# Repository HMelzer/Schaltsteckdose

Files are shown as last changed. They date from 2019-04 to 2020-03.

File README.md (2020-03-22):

# Funkschaltsteckdose für HomeMatic/RaspberryMatik

## Gehäuse
Auf der Basis des [ELV-Gehäuses OM54](https://de.elv.com/elv-design-stecker-steckdosen-gehaeuse-om-54-c-mit-tasterstoessel-und-led-leuchtfeld-083421)
und des dazugehörigen [Steckdoseneinsatzes](https://de.elv.com/schutzkontakt-stecker-steckdosen-einsatz-ohne-sicherungshalter-083422) wird hier eine Funk-Schaltsteckdose vorgestellt,
die auf der Grundlage von AsksinPP arbeitet und voll in das HomeMatic/RaspberryMatik-Programm integriert werden kann.

## Platine
Die Platine wurde mit KICAD entwickelt, die KICAD-Daten sind hier beigefügt.
Das nachfolgende Bild zeigt Vorder- und Rückseite der Leiterplatte, hier noch im Leiterplattenrahmen,
aus dem man die Leiterplatten spätestens dann trennen muss, wenn man den Steckdoseneinsatz montieren will.
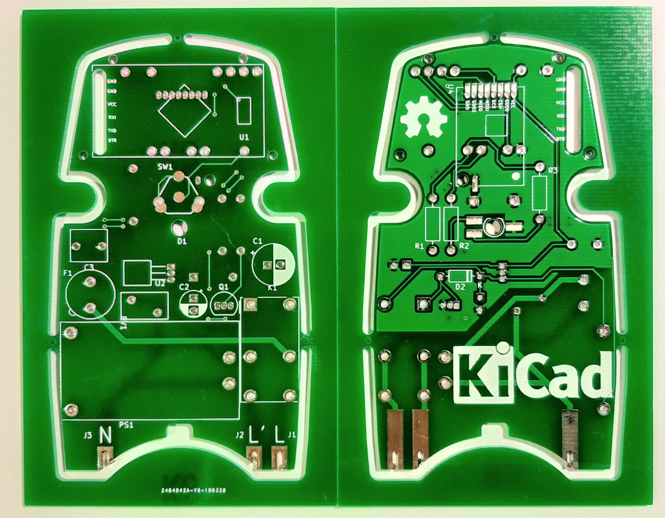
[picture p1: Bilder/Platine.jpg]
Leiterplatte


## Schaltung
Für die Stromversorgung wurde ein Baustein von Hi-Link verwendet, der primärseitig mit 100 - 240 V gespeist werden und sekundärseitig 12 V DC bei 0,25 A liefern kann.
[HMK-PM12](https://de.aliexpress.com/item/32960181700.html?spm=a2g0s.9042311.0.0.19304c4d0xYQv4).
Wegen der engen Platzverhältnisse kam ein Relais G6B-2214P der Fa. Omron mit 12 V Spulenspannung zum Einsatz, dass 5 A schalten kann.<br/>
Herzstück ist, wie in den meisten HomeMatic/RaspberryMatic-Projekten, ein ArduinoProMini in der 3,3 V - Variante, der eine große Verbreitung erlangt hat und bei vielen Anbietern zu bekommen ist.
Die erforderliche Spannung für diesen und den Sendebaustein erzeugt ein LDO aus der 12 V - Spannung.<br/>
Im Schaltplan sind alternativ zwei Sendebausteine aufgeführt.
Das ist zum einen der klassische CC1101, der in vielen Projekten zur Anwendung kommt.
Da es damit in der Vergangenheit immer wieder zu Problemen mit der Sende-/Empfangsfrequenz gekommen ist, vergleiche [Fehlerhafte CC1101 Module](https://asksinpp.de/Grundlagen/FAQ/Fehlerhafte_CC1101.html),
wurde hier in der praktische Ausführung ein anderes Modul, welches ebenfalls den CC1101 verwendet, eingesetzt.
Das Modul ist ein [E07_868MS10](http://www.ebyte.com/en/product-view-news.aspx?id=180) der Fa. Ebyte.

## Ausführung/Montage
Beim Zusammenfügen des Gehäuses und des Steckdoseneinsatzes hat es sich gezeigt, dass die Öffnung im Gehäusedeckel geringfügig nachgearbeitet werden muss, um den Steckdoseneinsatz passfähig montieren zu können.
Mit dem Gehäuse lose mitgeliefert werden der Tastereinsatz, ein Lichtleiter und ein "Knackfrosch", der als Taster dient. Beim Einsetzen des Lichtleiters in den Tastereinsatz ist ein wenig Fingerspitzengefühl erforderlich
und man sollte vorsichtig zu Werke gehen, um nichts abzubrechen.
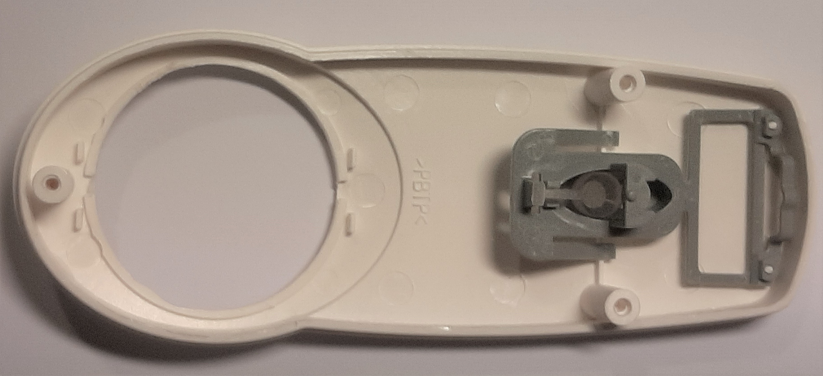
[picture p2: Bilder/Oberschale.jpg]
Oberschale
Das Bild zeigt die Oberschale mit montiertem Taster und Lichtleiter.<p/> <p/>
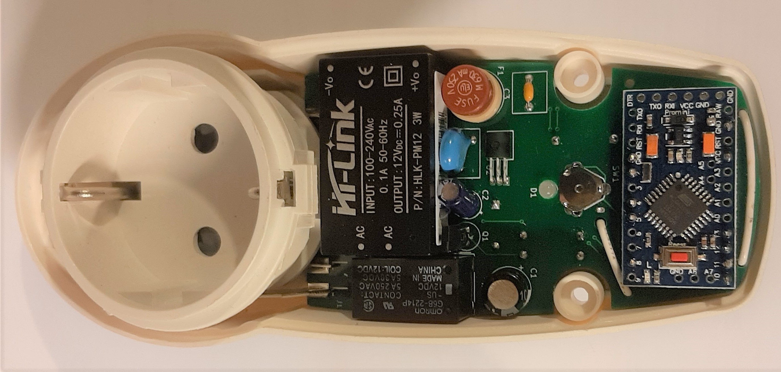
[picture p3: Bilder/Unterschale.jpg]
Unterschale
Im nachfolgenden Bild sieht man die Unterschale mit der bereits montierten Leiterplatte.<p/> <p/>
Der "Knackfrosch" wurde einfach in die dafür vorgesehenen Löcher auf der Vorderseite der Leiterplatte eingesetzt und die Laschen auf der Rückseite leicht umgebogen.
**Er darf nicht verlötet werden**.
Vor den eigentlichen Lötarbeiten empfiehlt es sich, die Leiterplatte aus dem Rahmen zu lösen und den Leiterplattenrand an den ehemaligen Verbindungsstellen zu glätten. Die Passfähigkeit im Gehäuse sollte anschließend geprüft werden.
Das sollte auch im Zusammenwirken mit dem Steckdoseneinsatz erfolgen und hierbei sollten auch gleich die Kontaktstreifen des Steckdoseneinsatzes an den Stellen gekennzeichnet werden, an denen diese gekürzt werden müssen.
Alle verwendeten Bauelemente sind als THT ausgeführt, sodass sich die Lötarbeiten einfach gestalten sollten. Die Verteilung auf Vorder- und Rückseite ist dem engen Platzverhältnis geschuldet, welches durch den integrierten Taster
bedingt ist.
Eine Besonderheit stellt die LED dar, da es sich um eine Bauform handelt, die zwei LED, rot und grün, in einem Gehäuse vereinigt.
Es handelt sich hierbei um eine 3 mm Diode, die von der Leiterplattenrückseite montiert werden muss, wobei diese nicht mehr als 1 mm auf der Vorderseite hervorstehen darf, da sich ansonsten der Taster nicht tief genug drücken lässt.
Alternativ kann man allerdings auch den Lichtleiter, beispielsweise mittels Dremel, um ca. 2 mm kürzen. Die Anschlussdrähte der Diode sind dabei nahe am Gehäuse zu biegen. Auf die richtige Verschaltung der beiden Dioden ist zu achten. Im Projekt zum Einsatz kam eine **EVL 209SURSYGW** (Reichelt Elektronik).
Dafür gilt auch der Aufdruck auf der Platine.<br/>
Bevor der ArduinoProMini mit allen dafür vorgesehenen Stiften mit der Leiterplatte verlötet wird, muss man die Stiftleiste (8 x 1,27 mm) für den E07_868MS10 aufsetzen und verlöten, da die Lötpunkte unter dem Arduino zu liegen kommen.
Die Anschlussstifte für den ArduinoProMini sollten in dem Bereich, wo diese vom E07_868MS10 überdeckt werden, nicht so lang ausfallen, damit es keine Kurzschlüsse gibt. Der E07_868MS10 selbst wird dann mittels der Stiftleiste 8 x 1,27 mm
und einem einzelnen Stift für den Masseanschluss auf der Leiterplatte verlötet. Dadurch erhält der E07_868MS10 auch gleich den nötigen Abstand zur Leiterplatte.
Die erforderliche Antenne wird durch einen Schaltdraht der Länge 83 mm gebildet, welcher von oben durch das vorhandene Loch rechts neben dem "Knackfrosch" gesteckt und an dem verbliebenen Anschluss am E07_868MS10 angelötet wird.
Das freie Ende des Schaltdrahtes wird dann wechselseitig durch die vorhandenen Löcher neben und oberhalb des ArduinoProMini geführt.<p/>
Das folgende Bild zeigt die bestückte Rückseite mit bereits montiertem Steckdoseneinsatz. Die montierte LED ist gut zu erkennen, ebenso das Funkmodul und die verlegte Antenne.
Das geänderte Leiterplattenlayout oben links ist in den Daten bereits korrigiert.<p/>
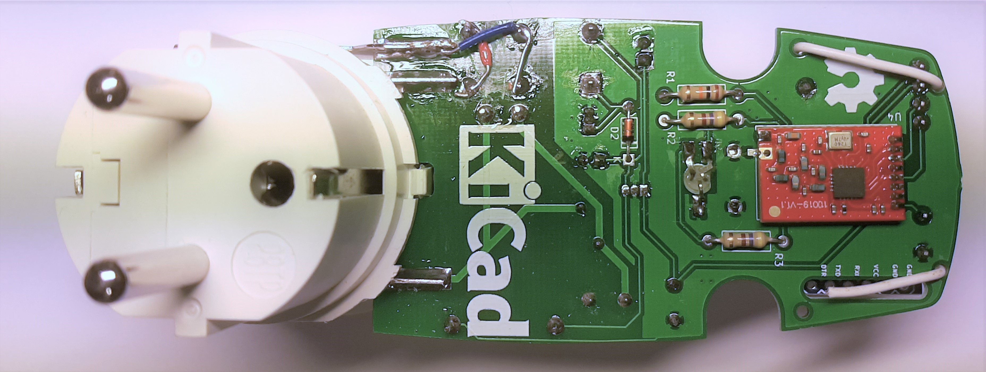
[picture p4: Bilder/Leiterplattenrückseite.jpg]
Leiterplattenrückseite
<p/>
Zum Schluss wird der Steckdoseneinsatz mit der Leiterplatte verlötet. Um die spätere Passfähigkeit zu erhalten, ist es empfehlenswert, Leiterplatte und Steckdoseneinsatz in das Gehäuse einzusetzen und die Laschen oberseitig mit wenig
Lötzinn zu fixieren. Nach der Entnahme aus dem Gehäuse müssen die Laschen großflächig, sowohl auf der Ober- wie auch auf der Unterseite mit der Leiterplatte verlötet werden.

## Programmierung
Die Datei [HM-LC-Sw1-Pl-DN-R1.ino](https://github.com/HMelzer/Schaltsteckdose/blob/master/HM-LC-Sw1-Pl-DN-R1/HM-LC-Sw1-Pl-DN-R1.ino) enthält das entsprechende Programm, welches in den ArduinoProMini eingespielt werden muss.
Im Bereich ab Zeile 43 sind wie immer die entsprechenden Anpassungen für "Device ID" und "Device Serial" vorzunehmen.<br/>
Die eigentliche Programmierung erfolgt dann mittels der Programmiersoftware für den Arduino in der entsprechend neusten Version und einem FTDI Adapter FT232RL USB zu TTL.
Bei Verwendung eines solchen, beispielsweise der Fa. AZ-Delivery, kann man die daran vorhandene Stiftleiste gleich in die dafür vorgesehenen Löcher am ArduinoProMini stecken und so die Programmierung auf einfache Weise vornehmen.

## Anlernen
Nachdem man die Programmierung abgeschlossen und das Gehäuse mittels der mitgelieferten Schrauben geschlossen hat, kann man die erste Funktionsprobe vornehmen. Hat man die Schaltsteckdose mittels der Steckerstifte mit dem Stromnetz verbunden,
sollte zunächst das Ein- und wieder Ausschalten über den Taster möglich sein. Im Aus-Zustand sollte keine LED leuchten, im Ein-Zustand die grüne LED.<br/>
Das Anlernen erfolgt nun in der bekannten Weise, dass man in der Zentrale die Anlernfunktion für Geräte startet und an der Schaltsteckdose den Taster kurz betätigt (rote LED blinkt), wobei dadurch die Schaltsteckdose ebenfalls in den Anlernmodus
versetzt wird und nach kurzer Zeit die blinkende LED das Blinken einstellen sollte. Nachdem der Anlernmodus in der Zentrale abgelaufen ist, sollte sich das neue Gerät im Posteingang der Zentrale wiederfinden,
woraus es dann übernommen, eingestellt und programmiert werden kann.

## Lizenz
Der Inhalt dieses Repository unterliegt der aktuellen Lizenz nach Creative Commons - [https://creativecommons.org/licenses/by-nc-sa/4.0/deed.de](https://creativecommons.org/licenses/by-nc-sa/4.0/deed.de).

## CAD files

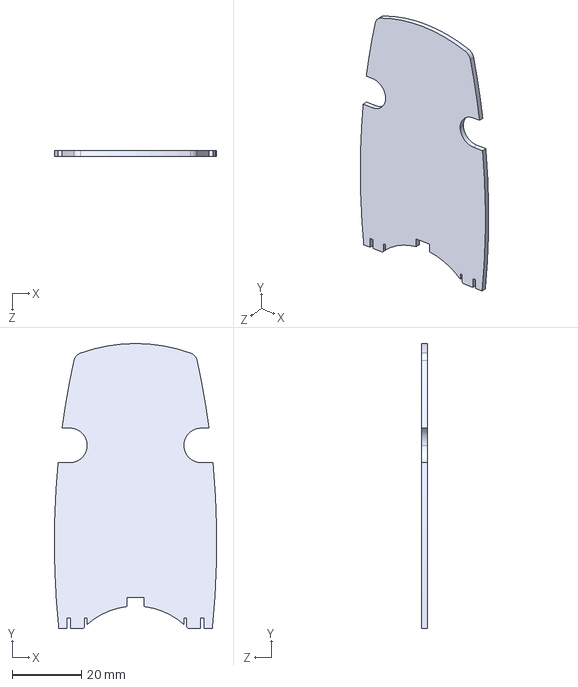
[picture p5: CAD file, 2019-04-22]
Leiterplattenkontur.STEP
47.0 x 82.5 x 1.60 mm

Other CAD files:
Leiterplattenkontur.DXF
Leiterplattenkontur.SLDPRT

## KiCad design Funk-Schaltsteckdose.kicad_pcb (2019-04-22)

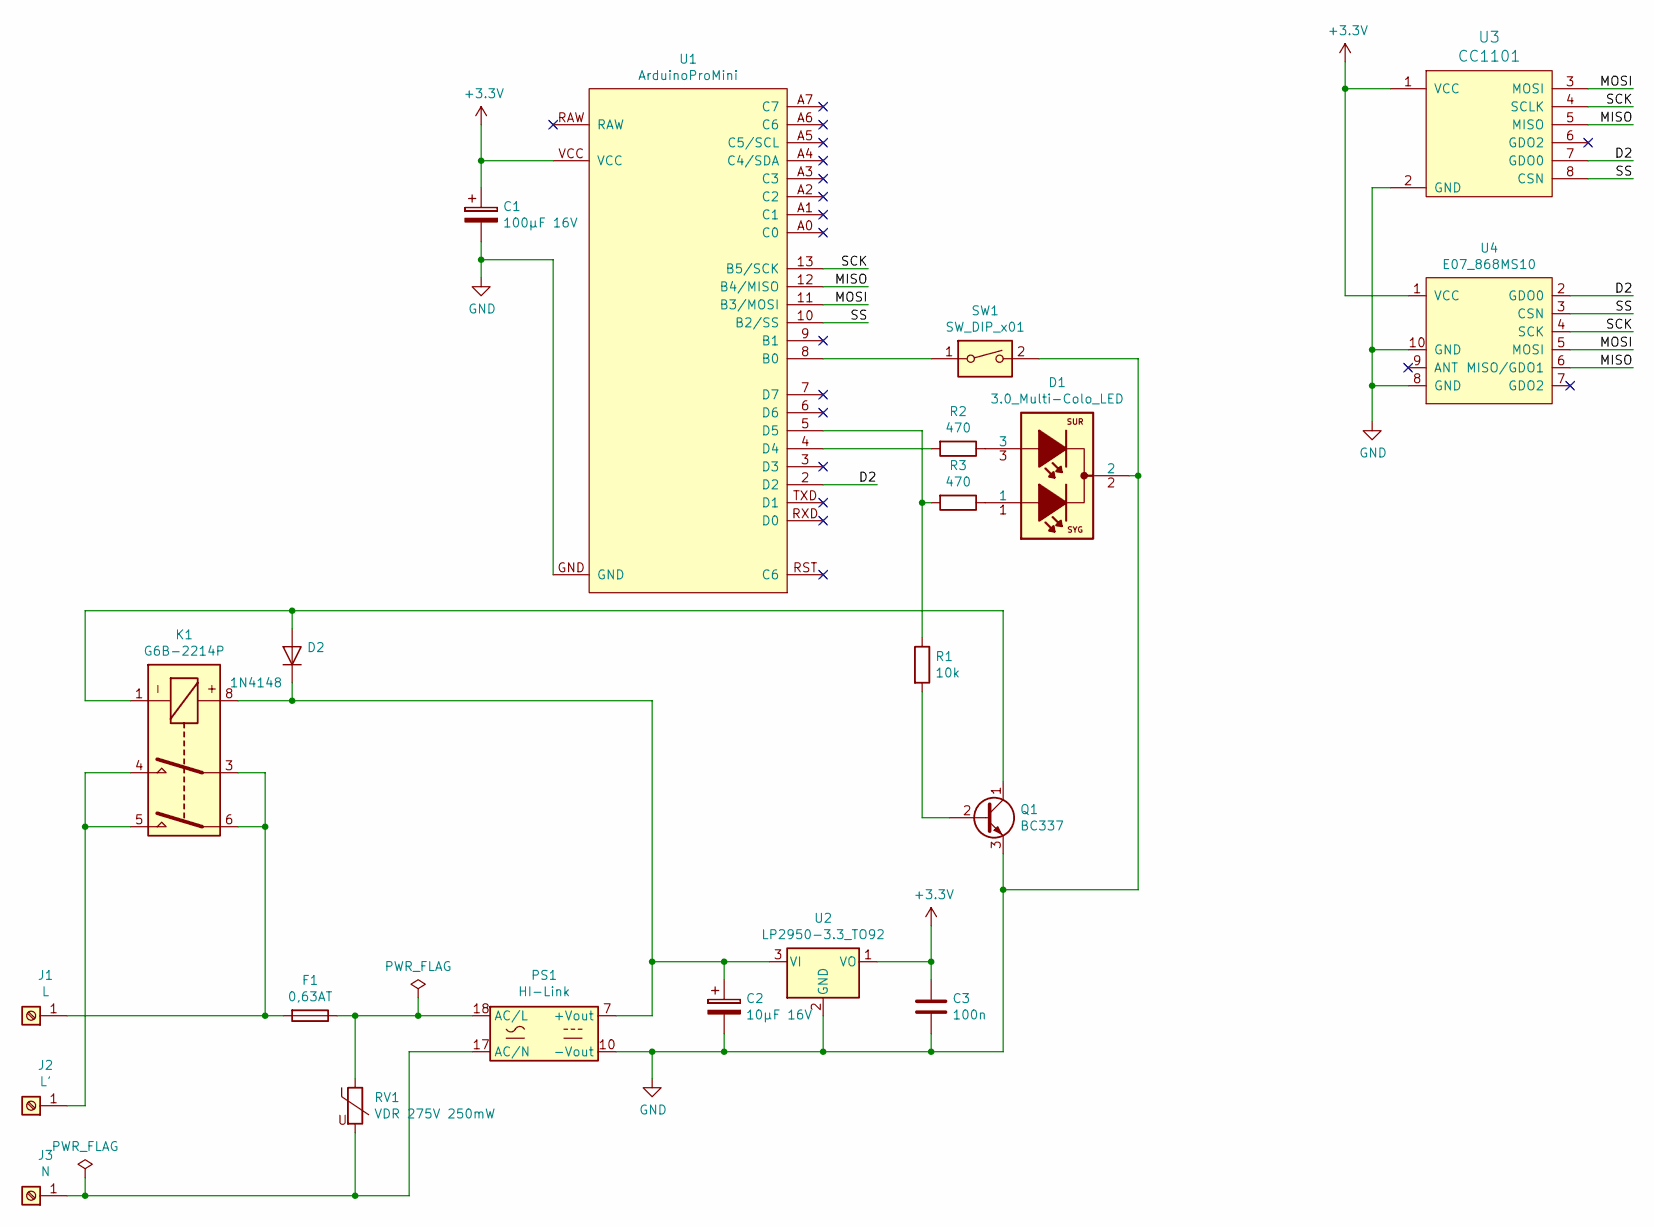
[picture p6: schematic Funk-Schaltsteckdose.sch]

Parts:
C1: 100µF 16V; CP_Radial_D8.0mm_P2.50mm
C2: 10µF 16V; CP_Radial_D5.0mm_P2.50mm
C3: 100n; C_Rect_L7.0mm_W6.0mm_P5.00mm
D1: 3.0_Multi-Colo_LED; Durchsteck_LED_THT_3,0
D2: 1N4148; D_DO-35_SOD27_P7.62mm_Horizontal
F1: 0,63AT; Fuseholder_TR5_Littelfuse_No560_No460
J1: L; Kontaktstreifen
J2: L'; Kontaktstreifen
J3: N; Kontaktstreifen
K1: G6B-2214P; Relay_DPST_Omron_G6B-2214
PS1: HI-Link
Q1: BC337; TO-92_Inline
R1: 10k; R_Axial_DIN0207_L6.3mm_D2.5mm_P10.16mm_Horizontal
R2, R3: 470; R_Axial_DIN0207_L6.3mm_D2.5mm_P10.16mm_Horizontal
RV1: VDR 275V 250mW; RV_Disc_D9mm_W5.2mm_P5mm
SW1: SW_DIP_x01; Schaltkontakt
U1: ArduinoProMini; ArduinoProMini_modif.
U2: LP2950-3.3_TO92; TO-92_Inline_Horizontal1
U3: CC1101
U4: E07_868MS10

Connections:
+3V3: C1.1, C3.1, U1.VCC, U2.1 (VO), U3.1 (VCC), U4.1 (VCC)
/D2: U1.2 (D2), U3.7 (GDO0), U4.2 (GDO0)
/MISO: U1.12 (B4/MISO), U3.5 (MISO), U4.6 (MISO/GDO1)
/MOSI: U1.11 (B3/MOSI), U3.3 (MOSI), U4.5 (MOSI)
/SCK: U1.13 (B5/SCK), U3.4 (SCLK), U4.4 (SCK)
/SS: U1.10 (B2/SS), U3.8 (CSN), U4.3 (CSN)
GND: C1.2, C2.2, C3.2, D1.2, PS1.10 (-Vout), Q1.3 (E), SW1.2, U1.GND, U2.2 (GND), U3.2 (GND), U4.8 (GND), U4.10 (GND)
unnamed: C2.1, D2.1 (K), K1.8, PS1.7 (+Vout), U2.3 (VI)
unnamed: D1.1, R3.1
unnamed: D1.3, R2.1
unnamed: D2.2 (A), K1.1, Q1.1 (C)
unnamed: F1.1, PS1.18 (AC/L), RV1.1
unnamed: F1.2, J1.1, K1.3, K1.6
unnamed: J2.1, K1.4, K1.5
unnamed: J3.1, PS1.17 (AC/N), RV1.2
unnamed: Q1.2 (B), R1.2
unnamed: R1.1, R3.2, U1.5 (D5)
unnamed: R2.2, U1.4 (D4)
unnamed: SW1.1, U1.8 (B0)

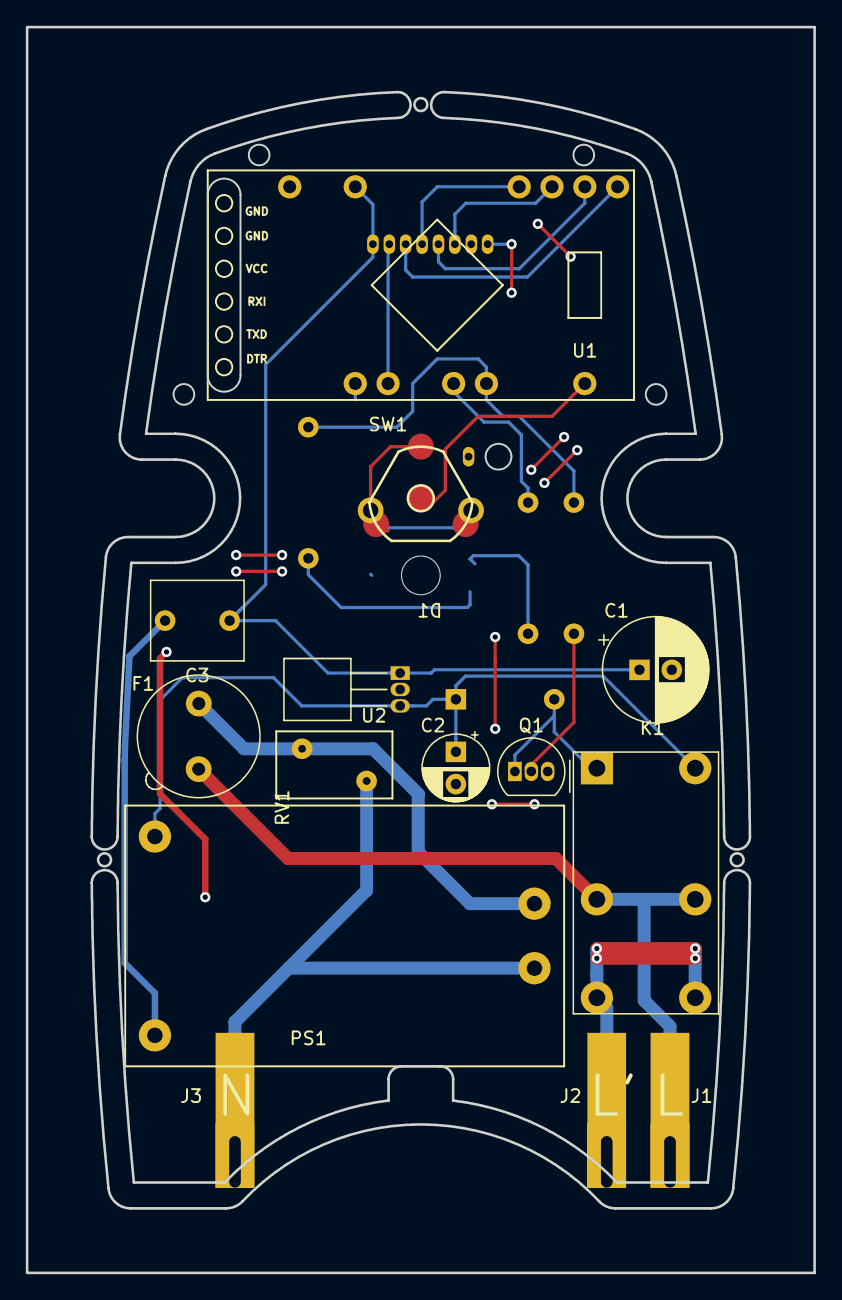
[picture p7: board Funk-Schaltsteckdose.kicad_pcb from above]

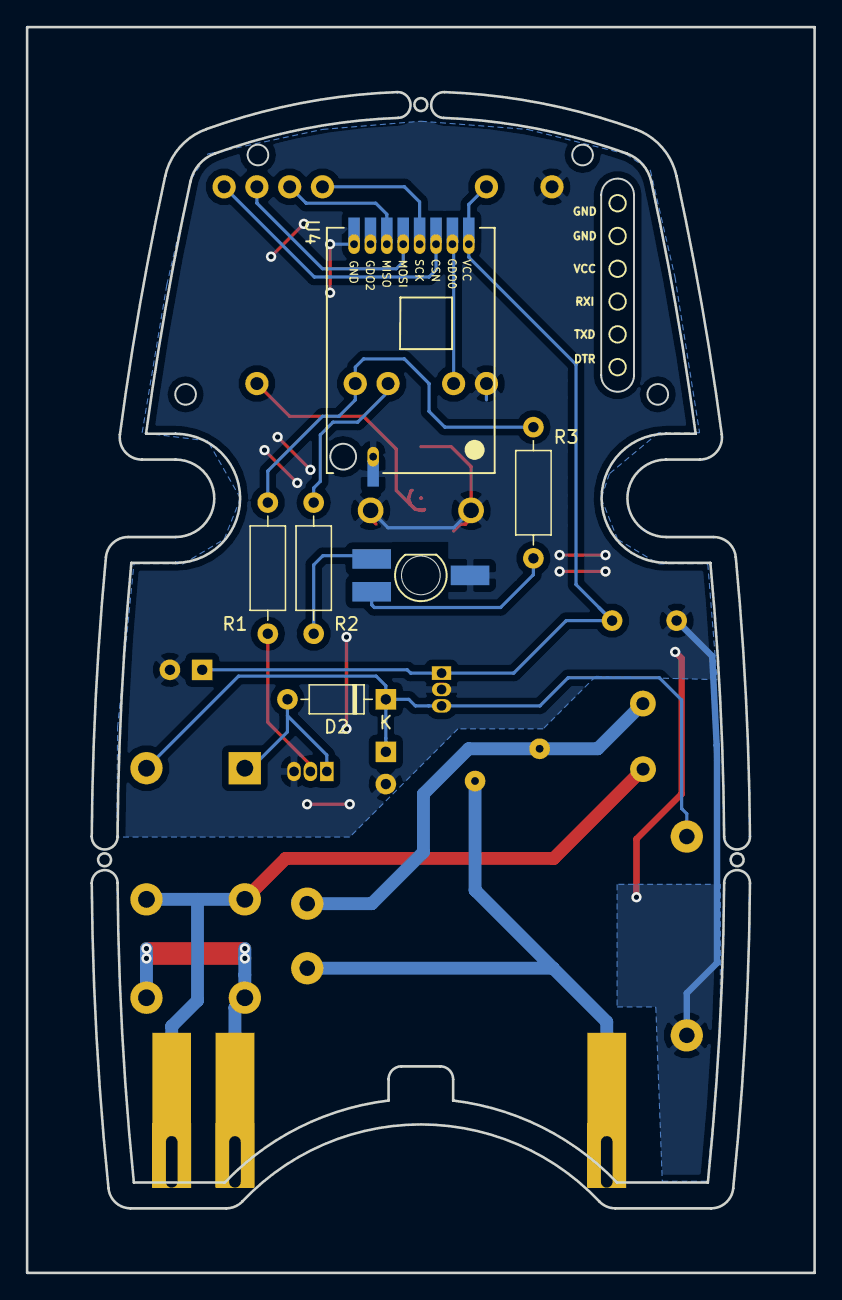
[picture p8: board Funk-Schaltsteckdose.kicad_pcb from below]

Board: 2 copper layers, 61.0 x 96.5 mm, 20 parts (5 on the bottom side), 19 nets.

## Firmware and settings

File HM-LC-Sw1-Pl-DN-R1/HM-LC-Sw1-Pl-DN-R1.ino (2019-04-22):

//- -----------------------------------------------------------------------------------------------------------------------
// AskSin++
// 2016-10-31 papa Creative Commons - http://creativecommons.org/licenses/by-nc-sa/3.0/de/
//- -----------------------------------------------------------------------------------------------------------------------

// define this to read the device id, serial and device type from bootloader section
// #define USE_OTA_BOOTLOADER

// number of relays by defining the device


#define CFG_LOWACTIVE_BYTE 0x00
#define CFG_LOWACTIVE_ON   0x01
#define CFG_LOWACTIVE_OFF  0x00

#define DEVICE_CONFIG CFG_LOWACTIVE_OFF

#define EI_NOTEXTERNAL
#include <EnableInterrupt.h>
#include <AskSinPP.h>
#include <LowPower.h>

#include <Switch.h>

// we use a Pro Mini
// Arduino pin for the LED
// D4 == PIN 4 on Pro Mini
#define LED_PIN 4
// Arduino pin for the config button
// B0 == PIN 8 on Pro Mini
#define CONFIG_BUTTON_PIN 8

#define RELAY1_PIN 5


// number of available peers per channel
#define PEERS_PER_CHANNEL 8


// all library classes are placed in the namespace 'as'
using namespace as;

// define all device properties
const struct DeviceInfo PROGMEM devinfo = {
  {0xFF, 0X11, 0X30},     // Device ID
  "HMLCSw1001",           // Device Serial
  {0x00,0xd8},            // Device Model
  0x25,                   // Firmware Version
  as::DeviceType::Switch, // Device Type
  {0x01, 0x00}            // Info Bytes
};

/**
   Configure the used hardware
*/
typedef AvrSPI<10, 11, 12, 13> RadioSPI;
typedef AskSin<StatusLed<4>, NoBattery, Radio<RadioSPI, 2> > Hal;

// setup the device with channel type and number of channels
typedef MultiChannelDevice<Hal, SwitchChannel<Hal, PEERS_PER_CHANNEL, List0>, 1> SwitchType;

Hal hal;
SwitchType sdev(devinfo, 0x20);
ConfigToggleButton<SwitchType> cfgBtn(sdev);

void initPeerings (bool first) {
  // create internal peerings - CCU2 needs this
  if ( first == true ) {
    HMID devid;
    sdev.getDeviceID(devid);
    for ( uint8_t i = 1; i <= sdev.channels(); ++i ) {
      Peer ipeer(devid, i);
      sdev.channel(i).peer(ipeer);
    }
  }
}

void initModelType () {
  uint8_t model[2];
  sdev.getDeviceModel(model);
  sdev.channels(1);
}

void setup () {
  DINIT(57600, ASKSIN_PLUS_PLUS_IDENTIFIER);
  bool first = sdev.init(hal);
  sdev.channel(1).init(RELAY1_PIN, false);

  buttonISR(cfgBtn, CONFIG_BUTTON_PIN);

  initModelType();
  initPeerings(first);
  sdev.initDone();
}

void loop() {
  bool worked = hal.runready();
  bool poll = sdev.pollRadio();
  if ( worked == false && poll == false ) {
    hal.activity.savePower<Idle<> >(hal);
  }
}

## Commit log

2019-04-22 Alles hinzugefügt
    [Funk-Schaltsteckdose-B.Cu.gbr, Funk-Schaltsteckdose-B.Mask.gbr, Funk-Schaltsteckdose-B.Paste.gbr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]
2019-04-22 Datein gelöscht
    [HI-Link.SLDPRT, HI-Link.STL, Knackfrosch.DXF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]
2020-03-09 Layout angepasst
    [Funk-Schaltsteckdose-B.Cu.gbr, Funk-Schaltsteckdose-B.Mask.gbr, Funk-Schaltsteckdose-B.Paste.gbr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]
2020-03-09 Revert "Layout angepasst"
    This reverts commit ff7744db74a23c470d7ae99f610fa08b87265f2a.
    [Funk-Schaltsteckdose-B.Cu.gbr, Funk-Schaltsteckdose-B.Mask.gbr, Funk-Schaltsteckdose-B.Paste.gbr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]
2020-03-09 Daten angepasst
    [Funk-Schaltsteckdose-B.Cu.gbr, Funk-Schaltsteckdose-B.Mask.gbr, Funk-Schaltsteckdose-B.Paste.gbr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]
